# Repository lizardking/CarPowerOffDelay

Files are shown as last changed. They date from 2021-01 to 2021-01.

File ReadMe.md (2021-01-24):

Car Turn Off Delay Relay Board
==============================
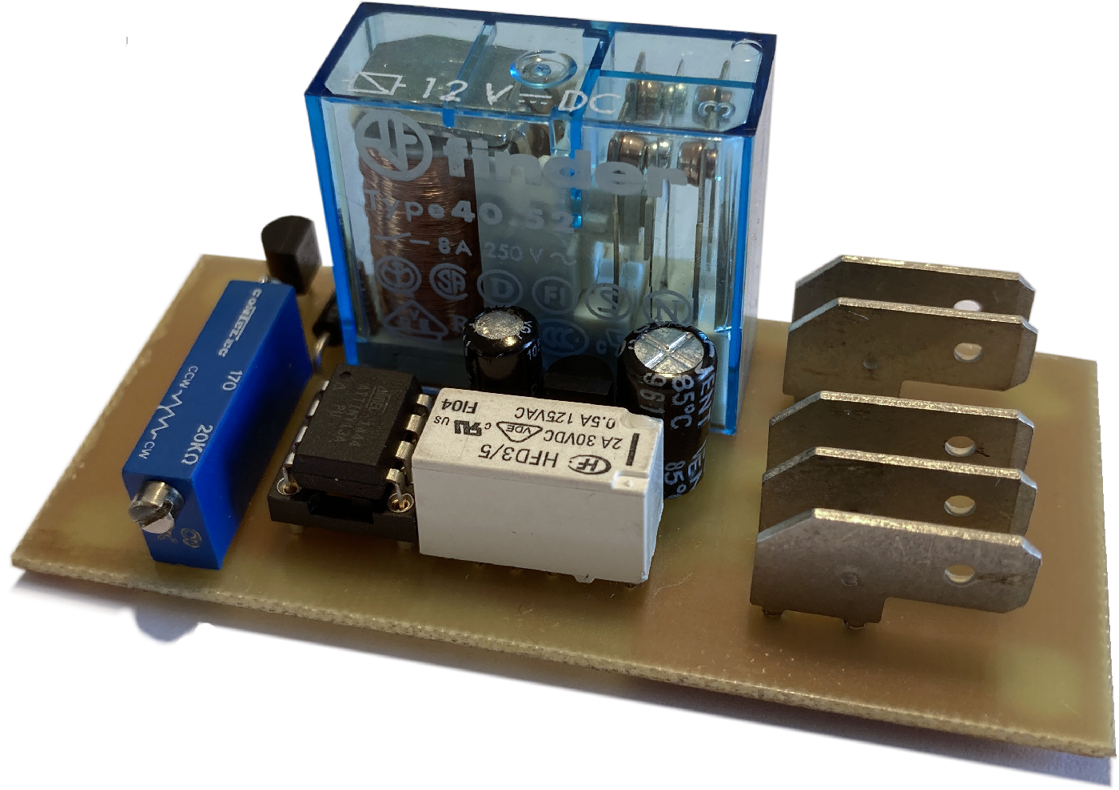
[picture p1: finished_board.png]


IDK how many times chargers for mobiles and other devices that were connected to out classic cars lighter plugs have drained 
the cars batteries to a point where is was impossible to start the car again (usualy after the car had not been used for a few weeks).

This board overcomes this problem by disconnecting the power supply to the lighter plug (or anything else) after a defineable period 
(up to approx. 135minutes) after the cars iginition has been turned off. Like this it is still possible to charges mobiles and the like
for a while after the car had been stopped, but not to a point where the cars battery is drained to much.

Once the board turns off the power on its output it also disconnects itself completely from the power supply and wont consume even the 
slightest bit off power in this state.

Design
------

The board was designed with the Eagle PCB editor. So if you want to make changes you'll need this software.

The boart uses a ATTiny microcontroller as its brain. This allows for easy modification of the boards behaviour. The firmware for the 
microcontroller has been written very quick and dirty with Bascom. Bascom might not be a nice solution, but for simple stuff like this
it is good enough. The hex and bin files for upload to the microcontroller are contained in the firmware folder, so you will not need 
Bascom and you can just use whatever tool you prefer to upload the firmware.

The parts on the board are all simple, stanard components which should be readily available at almost every electronic parts store.
The connectores are FASTON Automotive Connectors.

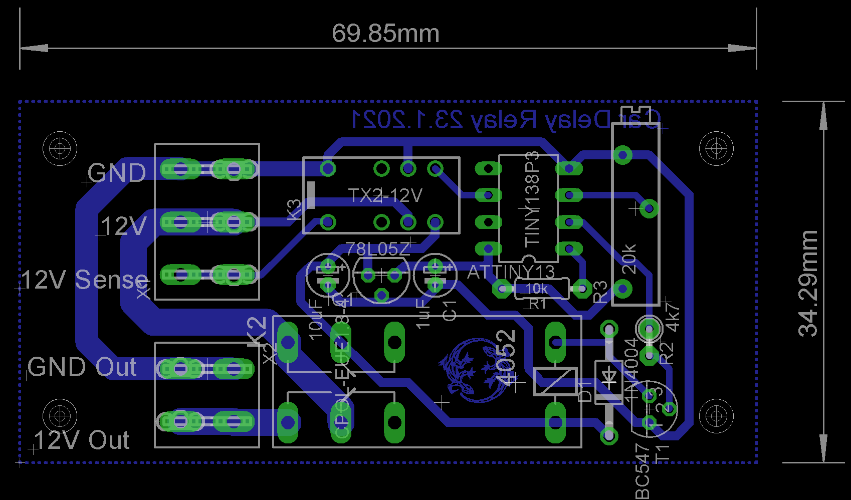
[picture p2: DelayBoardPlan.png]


Installing the board
--------------------

* Connect the GND and 12V connectors to the battery of your car. They must have a uninterupted line to the battery, so no switch or the
  like on the way to the battery.
* Connect 12V Sense to the ignition switch of your car or any other line which will have 12V as long as the car is running and which will
  turn of when the engine is stopped.
* Connect 12V Out and GND Out to the lighter plug or any other appliance you want to turn off with a delay.

Configuring the time out/delay
------------------------------

To set the desired turn off delay,do the following:

* Turn the trimmer on the board to a value which is well above the desired target time. Max. time is when the timer is fully at the 5V end.
* Start the timer with a 12V pulse on the sense input and disconnect the sense input immediately.
* Let the time you want the timer to run elapse, e.g. use a time on your phone.
* Once the desired time has elapsed turn the trimer back towards the GND end till the timer stops/relay turns off.

Bingo! You have set the desired turn off delay time.

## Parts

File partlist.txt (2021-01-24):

Partlist

Exported from CarDelayRelay.sch at 23.01.2021 15:21:43

EAGLE Version 6.4.0 Copyright (c) 1988-2013 CadSoft

Assembly variant: 

Part          Value          Device        Package  Library          Sheet

C1            1uF            CPOL-EUE1.8-4 E1,8-4   0_Standard-Parts 1
CPOL-EUE1.8-4 10uF           CPOL-EUE1.8-4 E1,8-4   0_Standard-Parts 1
D1            1N4004         1N4004        DO41-10  diode            1
IC1           78L05Z         78L05Z        TO92     linear           1
K2            4052           4052          F4052    Relay            1
K3            TX2-12V        TX2-12V       TX2      Relay            1
R1            10k            R-EU_0204/7   0204/7   0_Standard-Parts 1
R2            4k7            R-EU_0207/2V  0207/2V  0_Standard-Parts 1
R3            20k            R-TRIMM43P    RTRIM43P 0_Standard-Parts 1
T1            BC547          BC547         TO92     transistor       1
U$1           TINY138P3      TINY138P3     DIL08    0_avr            1
X1                           SH5-3         SH5-3    con-rib          1
X2                           SH5-2         SH5-2    con-rib          1

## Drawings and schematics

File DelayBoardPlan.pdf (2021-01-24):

69.85mm

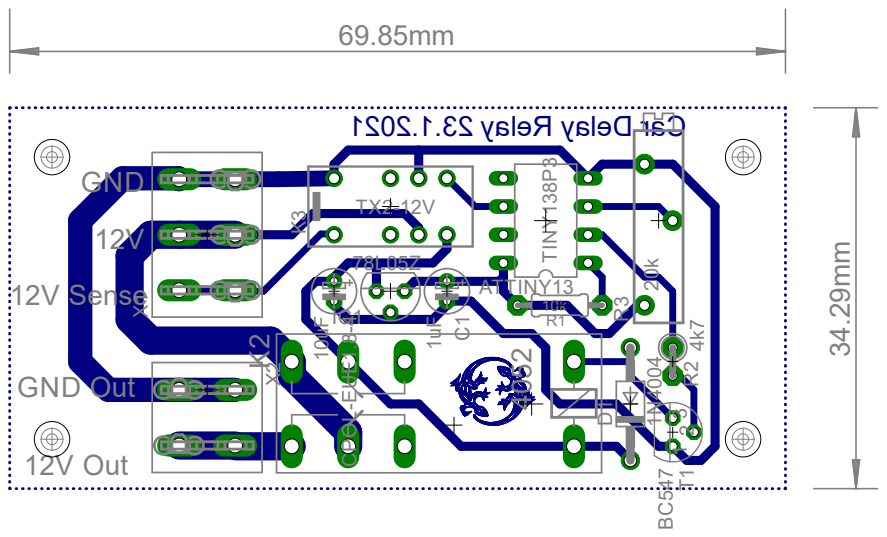
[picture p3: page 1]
GND; 12V Sense; GND Out; 12V Out; ATTINY13; CPOL⁻EUE¹.8⁻4; C¹X¹; D¹ R³ TINY¹³⁸P³; 4k7 BC⁵⁴⁷; 1N⁴⁰⁰⁴ ²⁰k

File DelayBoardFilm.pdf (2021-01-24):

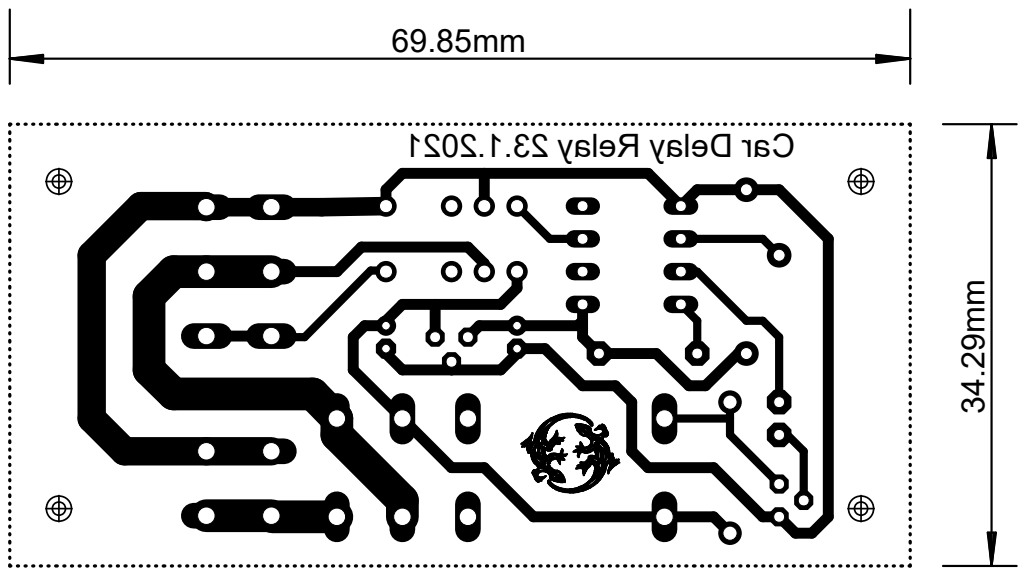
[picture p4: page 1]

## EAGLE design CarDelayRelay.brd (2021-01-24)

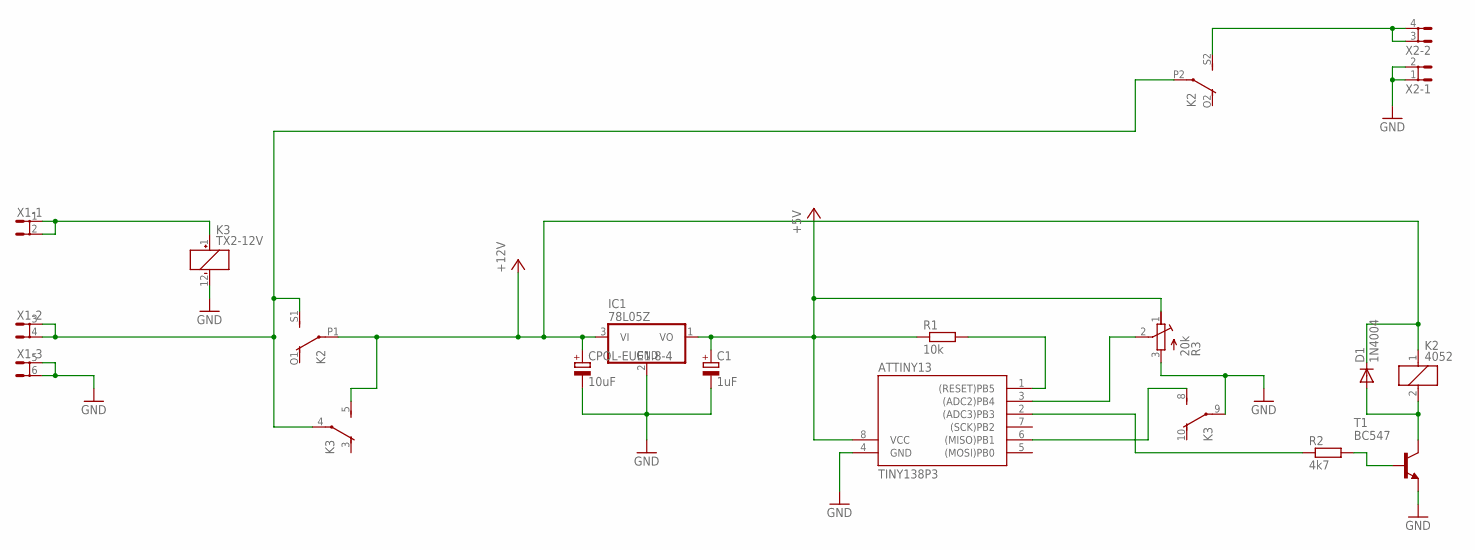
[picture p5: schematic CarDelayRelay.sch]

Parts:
ATTINY13: TINY138P3; DIL08
C1: 1uF; E1,8-4
CPOL-EUE1.8-4: 10uF; E1,8-4
D1: 1N4004; DO41-10
IC1: 78L05Z; TO92
K2: 4052; F4052
K3: TX2-12V; TX2
R1: 10k; 0204/7
R2: 4k7; 0207/2V
R3: 20k; RTRIM43P
T1: BC547; TO92
X1: SH5-3
X2: SH5-2

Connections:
+5V: ATTINY13.8 (VCC), C1.+, IC1.1 (VO), R1.1, R3.1 (A)
GND: ATTINY13.4 (GND), C1.-, CPOL-EUE1.8-4.-, IC1.2 (GND), K3.9, K3.12 (-), R3.3 (E), T1.1 (E), X1.5 (1), X1.6 (2), X2.1, X2.2
IC1: ATTINY13.6 ((MISO)PB1), K3.8 (S)
unnamed: K3.1 (+), X1.1, X1.2
unnamed: ATTINY13.1 ((RESET)PB5), R1.2
unnamed: ATTINY13.2 ((ADC3)PB3), R2.1
unnamed: R2.2, T1.2 (B)
unnamed: D1.A, K2.2, T1.3 (C)
unnamed: K2.P2, K2.S1 (S), K3.4, X1.3 (1), X1.4 (2)
unnamed: K2.S2 (S), X2.3 (1), X2.4 (2)
unnamed: ATTINY13.3 ((ADC2)PB4), R3.2 (S)
VCC: CPOL-EUE1.8-4.+, D1.C, IC1.3 (VI), K2.1, K2.P1, K3.5 (S)

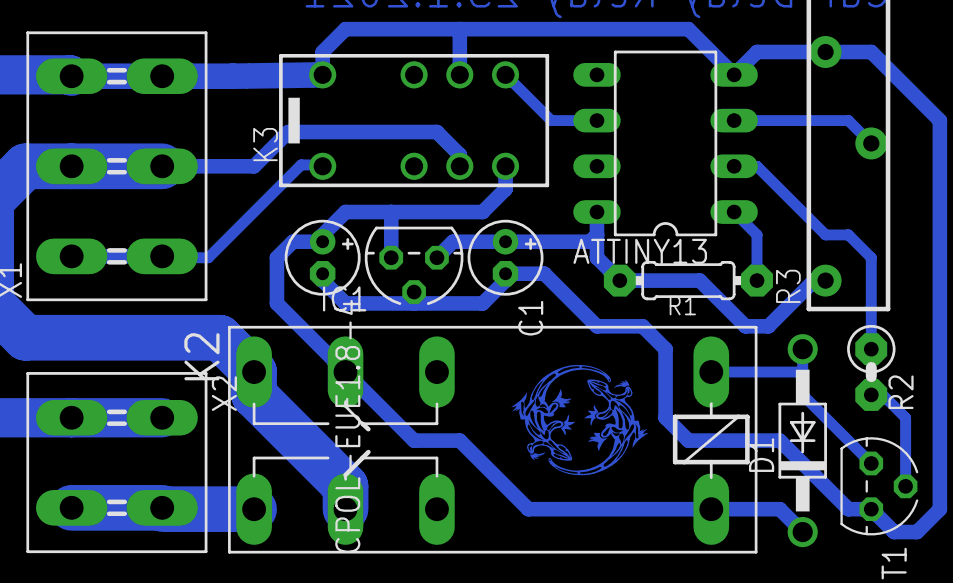
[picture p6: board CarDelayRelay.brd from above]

Board: 2 copper layers, 14 parts (0 on the bottom side), 12 nets.

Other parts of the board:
CPOL-EUE1.8-1: BOTTOM_DOUBLE_LIZARD_300

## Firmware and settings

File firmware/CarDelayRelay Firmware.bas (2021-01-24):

'************************************************************************************
'** Car delay relay firmware
'************************************************************************************
'To set the desired turn off delay,do the following:
'- Put the trimmer on the board to a value which is well above the desired
'  target time. Max. time is when the timer is fully at the 5V end
'- Start the timer with a 12V pulse on the sense input
'- Let the time you want the timer to run elapse,
'- Now turn the trimer back towards the GND end till the timer stops/relay turns off.
'Bingo! You have set the desired turn off delay time.
'
'The code below is has been written for Bascom. Dead ugly, but working ;)
'Tom 23.1.2021


'Just some general settings
$regfile = "attiny13.dat"
$crystal = 1200000
$hwstack = 16
$swstack = 5
$framesize = 16


'Relay
Relay alias PORTB.3
config PORTB.3=OUTPUT
Relay=1


'Digital input for power sense
Sense alias PINB.1
config PORTB.1=input
PORTB.1=1


'Analog input for trimmer
config portb.4=input  'Poti
const adcchannel=2

Config Adc = Single , Prescaler = Auto
Start Adc


'Variables

dim ElapsedTime as Word
dim AdcValue as Word
ElapsedTime=0


'loop

do
   if sense=0 then
     'As long as power is sensed time does not elapse
     ElapsedTime=0
     Relay=1
   else
      'No power is sensed
      'Compare elapsed time to value from ADC.
      'ADC returns 0 - 1023 which is multiplied by 8 giving a usable range from 0 - 8184 seconds (approx.136 minutes).
      Adcvalue=GetAdc(adcchannel)
      SHIFT Adcvalue, LEFT,3
      if adcValue<=ElapsedTime then
         'Elapsed time is greater than the value calculated from ADC.
         'Turn the relay power off. This will disconnect the output and the timer circuit,
         'so zero power is used after the timer has elapsed.
         Relay=0
      end if
      'Just wait a second before checking again
      waitms 1000
   end if
loop
